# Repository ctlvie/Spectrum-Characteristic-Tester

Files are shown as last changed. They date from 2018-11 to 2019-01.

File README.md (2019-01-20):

# 基于MSP430的频率特性测试仪

## 摘要

频率特性测试仪用于测量并显示被测网络的频率特性，本设计由一个正交扫频DDS信号源产生两路正交的正弦信号，正弦信号的频率为1kHz～1MHz，且步进频率可调。其中一路正弦信号作为待测网络的激励，待测网络的输出分别与原先的两路正交信号相乘，经过低通滤波器后即可得到直流分量，再经过ADS1115采样并由MSP430F5529计算待测网络的幅值和相频特性曲线。待测网络为截止频率分别为10kHz和100kHz的二阶有源高通和低通滤波器串联而成。

The spectrum characteristic tester is used to measure and display the frequency characteristics of the network under test. This design generates two orthogonal sinusoidal signals from a quadrature swept DDS signal source. The frequency of the sinusoidal signal is 1 kHz to 1 MHz, and the step frequency can be Tune. One of the sinusoidal signals is used as the excitation of the network to be tested. The output of the network to be tested is respectively multiplied by the original two orthogonal signals. After passing through the low-pass filter, the DC component can be obtained, and then sampled by ADS1115 and calculated by MSP430F5529. The amplitude and phase-frequency characteristics of the network. The network to be tested is a series of second-order active high-pass and low-pass filters with cutoff frequencies of 10 kHz and 100 kHz, respectively.

## 作品报告

<https://github.com/ctlvie/Spectrum-Characteristic-Tester/wiki/%E5%9F%BA%E4%BA%8EMSP430%E7%9A%84%E9%A2%91%E7%8E%87%E7%89%B9%E6%80%A7%E6%B5%8B%E8%AF%95%E4%BB%AA>

## 程序清单

|文件名 | 功能描述 |
|---|---|
|main.c  | 主函数 |
| AD9854.c |DDS模块的驱动 |
|ADS1115.c|外接ADC模块的驱动|
|Board.c|MSP430F5529LP板上资源的配置|
|Button.c|四个按键的配置|
|FormatConvert.c|数据类型转换|
|GlobalTimer.c|定时器TimerB(记录测量用时)的配置|
|KeyBoard.c|外接4*4矩阵键盘的配置|
|LCD12864.c|液晶屏的驱动|
|ProcessModule.c|进行数据处理、计算、绘图|

## 系统结构

系统结构

## 实物图

实物图

曲线图

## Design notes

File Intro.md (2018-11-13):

## 试题要求
### 1. 任务
设计制作一台频率特性测试仪，用于测量并显示“被测网络”的频率特性。

### 2. 基本要求
1. 设计制作“被测网络”，其输入、输出阻抗均为 50Ω，该网络由截止频率10kHz的二阶有源高通滤波器与截止频率100kHz的二阶有源低通滤波器串联而成，两个有源滤波器通带电压增益均为1;
2. 频率特性测试仪中，“采样调理”电路的输入阻抗50Ω。“扫频信号发生器”输出振幅为1V的正弦电压，其扫频范围1kHz~1MHz，频率步进 10Hz或1kHz可选，输出阻抗50Ω，并可用键盘设定点频输出;
3. 用“扫频法”测量扫频范围内“被测网络”的幅频 特性，并在LCD上显示幅频特性曲线、截止频率值，测量时间≤10秒
### 3. 发挥部分
1. 采用“点频法”测量“被测网络”的电压增益，以数字方式显示被测网络增益与频率，并用示波器标定，测量相对误差≤5%;测量频率由键盘设定;
2. 用“扫频法”测量扫频范围内“被测网络”的相频特性，并在LCD上显示相频特性曲线，测量时间≤10秒;
3. 用“点频法”测量“被测网络”的相移，以数字方式显示被测网络的相移与频率，并用示波器标定，测量相对误差≤5%;测量频率由键盘设定;
### 4. 说明
* 扫频法是指扫频信号发生器输出等幅线性扫频信号作为被测网络输入，同时对被测网络输出响应信号采样和计算，测得被测网络的频率 特性(网络增益与频率的关系)的方法。点频法是指单频信号输入时逐个测得频率特性的方法；负载调整率SI1=|𝑈o2−𝑈o1|/ Uo1，其 中UO1 为Io=0A 时的输出电压， UO2为IO=2A 时的输出电压;
* 采用128×64点阵等规格LCD显示幅频特性或相频特性曲线时，应同时显示“增益_频率”或 “相移_频率”的线性刻度(刻度的单位自定)。
* 被测网络制作在单独供电的独立电路板上，其输入、输出信号分别焊接到BNC插座上;频率特性测试仪输入、输出信号分别焊接到BNC插座上。被测网络与频率特性测试仪之间用两根长度20~30cm、50Ω、BNC接头电缆连接。

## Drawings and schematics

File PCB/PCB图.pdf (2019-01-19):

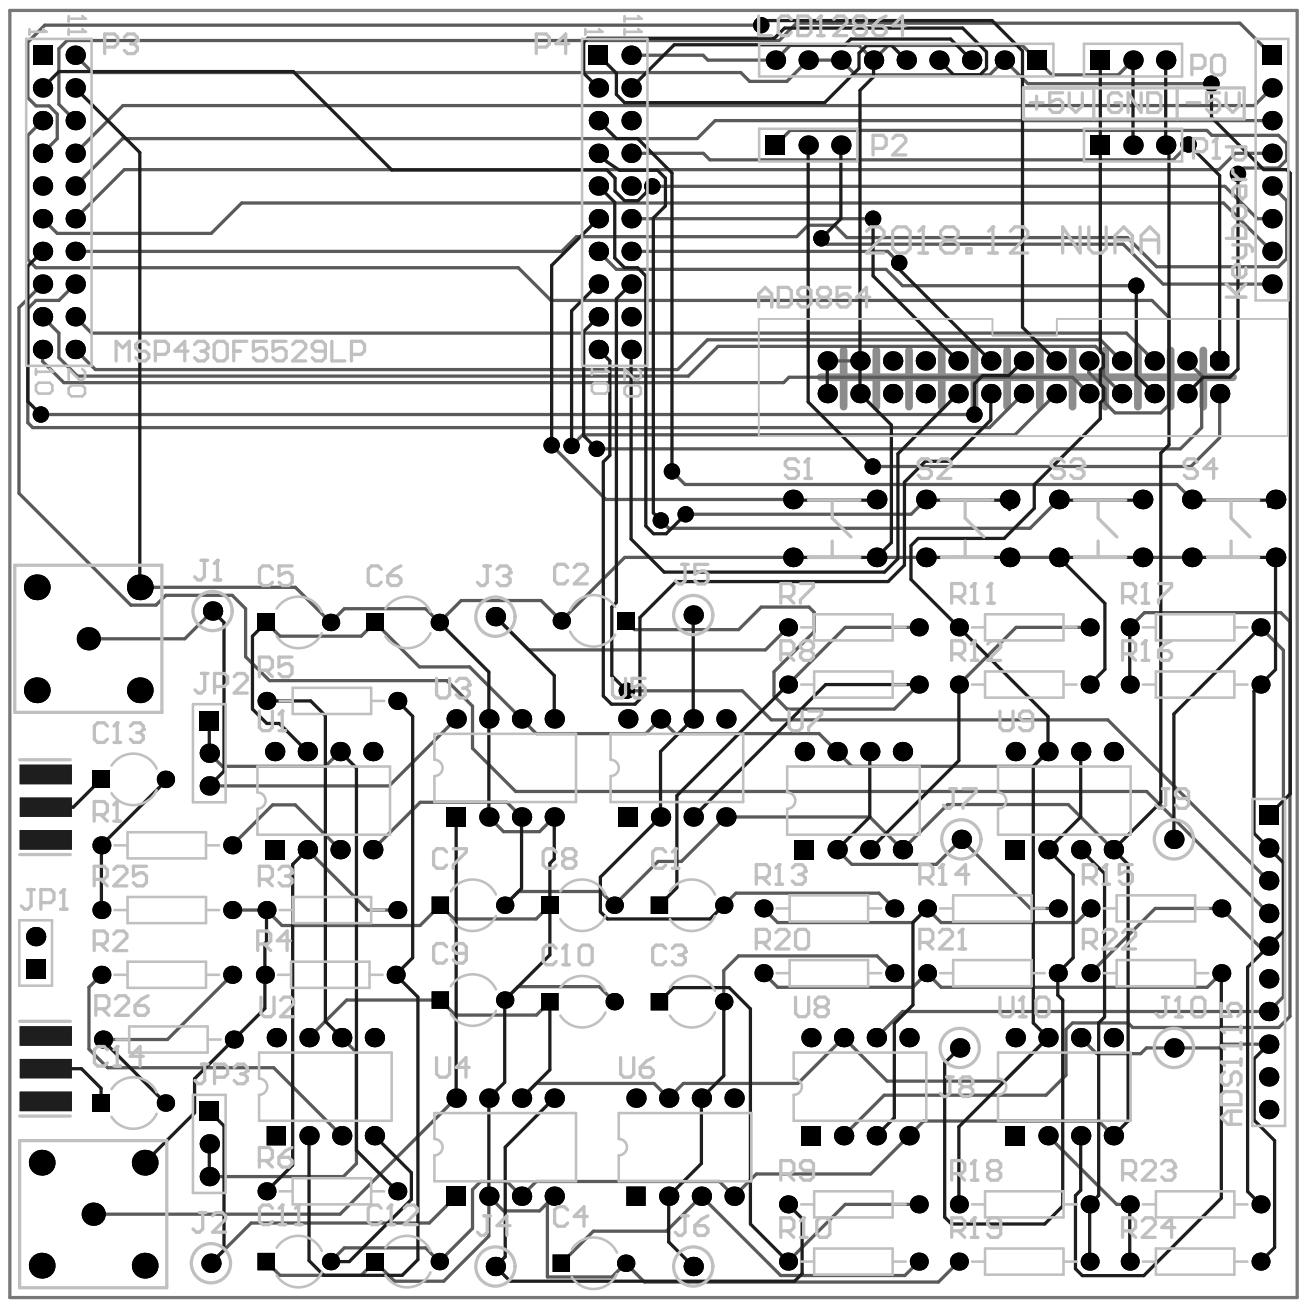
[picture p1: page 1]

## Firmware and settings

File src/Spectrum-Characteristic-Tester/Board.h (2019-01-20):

/*=======================================================
Author				  :				ctlvie
Email Address		  :				ctlvie@gmail.com
Filename			  :				Board.c
Date				  :			    2018-11-24
Description			  :				MSP430F5529LP ??????????

Modification History:
Date		By			Version		Description
----------------------------------------------------------
181124  	ctlvie		1.0			MSP430F5529LP ??????????
181216      ctlvie      2.0         Final Version
========================================================*/
#ifndef BOARD_H_
#define BOARD_H_

#define LED1_ON     P1OUT |= BIT0;
#define LED1_OFF    P1OUT |= BIT0;
#define LED2_ON     P4OUT |= BIT7;
#define LED2_OFF    P4OUT |= BIT7;

void initLED(void);
void initBoard(void);
#endif /* BOARD_H_ */

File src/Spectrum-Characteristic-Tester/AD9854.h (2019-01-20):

/*=======================================================
Author				  :				ctlvie
Email Address		  :				ctlvie@gmail.com
Filename			  :				AD9854.h
Date				  :			    2018-11-22
Description			  :				AD9854 DDS驱动程序

Modification History:
Date		By			Version		Description
----------------------------------------------------------
181122		ctlvie		1.0
181216      ctlvie      2.0         Final Version			
========================================================*/

#ifndef AD9854_H_
#define AD9854_H_
#ifndef uchar
#define uchar unsigned char
#endif
#ifndef ulong
#define ulong unsigned long
#endif
#ifndef uint
#define uint unsigned int
#endif

/*=======================================================
    接线方式:
    1. DataBus  ->  P3.0 ~ P3.7
    2. AddrBus  ->  P4.0 ~ P4.7
    3. RD       ->  P8.1
    4. WR       ->  P8.2
    5. UCLK     ->  P7.0
    6. RST      ->  P7.4
========================================================*/


#define IO_AD9854_DataBus_OUT       P3OUT
#define IO_AD9854_AddrBus_OUT       P4OUT
#define IO_AD9854_CtlBus1_OUT       P8OUT
#define IO_AD9854_CtlBus2_OUT       P7OUT
#define IO_AD9854_DataBus_DIR       P3DIR 
#define IO_AD9854_AddrBus_DIR       P4DIR
#define IO_AD9854_CtlBus1_DIR       P8DIR
#define IO_AD9854_CtlBus2_DIR       P7DIR

#define IO_AD9854_BIT_RD            BIT1
#define IO_AD9854_BIT_WR            BIT2
#define IO_AD9854_BIT_UCLK          BIT0
#define IO_AD9854_BIT_RST           BIT4



#define AD9854_DataBus              IO_AD9854_DataBus_OUT             //P3BIT0 ~ BIT7 为数据总线, 对应 D0 ~ D7
#define AD9854_AddrBus              IO_AD9854_AddrBus_OUT             //P4BIT0 ~ BIT5 为地址总线, 对应 A0 ~ A5
#define DIROUT_AD9854_DataBus       IO_AD9854_DataBus_DIR = BIT0 + BIT1 + BIT2 + BIT3 + BIT4 + BIT5 + BIT6 + BIT7 ;      //数据线IO口设为输出
#define DIROUT_AD9854_AddrBus       IO_AD9854_AddrBus_DIR = BIT0 + BIT1 + BIT2 + BIT3 + BIT4 + BIT5;     //地址线IO口设为输出
#define DIROUT_RD                   IO_AD9854_CtlBus1_DIR |= IO_AD9854_BIT_RD;    //P8.1 -> RD
#define DIROUT_WR                   IO_AD9854_CtlBus1_DIR |= IO_AD9854_BIT_WR;    //P8.2 -> WR
#define DIROUT_UDCLK                IO_AD9854_CtlBus2_DIR |= IO_AD9854_BIT_UCLK;    //P7.0 -> UCLK
#define DIROUT_RST                  IO_AD9854_CtlBus2_DIR |= IO_AD9854_BIT_RST;    //P7.4 -> RST
#define RD0_AD9854                  IO_AD9854_CtlBus1_OUT &= ~IO_AD9854_BIT_RD;   //RD使能(低有效)
#define RD1_AD9854                  IO_AD9854_CtlBus1_OUT |= IO_AD9854_BIT_RD;
#define WR0_AD9854                  IO_AD9854_CtlBus1_OUT &= ~IO_AD9854_BIT_WR;   //WR使能(低有效)
#define WR1_AD9854                  IO_AD9854_CtlBus1_OUT |= IO_AD9854_BIT_WR;
#define UCLK0_AD9854                IO_AD9854_CtlBus2_OUT &= ~IO_AD9854_BIT_UCLK;   //更新时钟
#define UCLK1_AD9854                IO_AD9854_CtlBus2_OUT |= IO_AD9854_BIT_UCLK;
#define RST0_AD9854                 IO_AD9854_CtlBus2_OUT &= ~IO_AD9854_BIT_RST;   //复位信号
#define RST1_AD9854                 IO_AD9854_CtlBus2_OUT |= IO_AD9854_BIT_RST;
//**************************以下部分为函数定义********************************

void WriteByte_AD9854(uchar addr,uchar dat);
void initAD9854(void);
void convertFreq(long Freq);
void setSinOutput(ulong Freq,uint Shape);
void convertFreq_double(double Freq);
void setSinOutput_double(double Freq,uint Shape);


//extern uchar FreqWord[6];              //6个字节频率控制字
//**********************以下为系统时钟以及其相关变量设置**************************

/*
      此处根据自己的需要设置系统时钟以及与其相关的因子，一次需且只需开启一个
      CLK_Set为时钟倍频设置，可设置4~20倍倍频，但最大不能超过300MHZ
      Freq_mult_ulong和Freq_mult_doulle均为2的48次方除以系统时钟，一个为长整形，一个为双精度型
*/

/*
#define      CLK_Set            4
const ulong  Freq_mult_ulong  = 3518437;
const double Freq_mult_doulle = 3518437.2088832;
*/

/*
#define      CLK_Set            5
const ulong  Freq_mult_ulong  = 2814750;
const double Freq_mult_doulle = 2814749.76710656;
*/

/*
#define      CLK_Set            6
const ulong  Freq_mult_ulong  = 2345625;
const double Freq_mult_doulle = 2345624.80592213;
*/

/*
#define      CLK_Set            7
const ulong  Freq_mult_ulong  = 2010536;
const double Freq_mult_doulle = 2010535.54793326;
*/

/*
#define      CLK_Set            8
const ulong  Freq_mult_ulong  = 1759219;
const double Freq_mult_doulle = 1759218.6044416;
*/

/*
#define      CLK_Set            9
const ulong  Freq_mult_ulong  = 1563750;
const double Freq_mult_doulle = 1563749.87061476;
*/

/*
#define      CLK_Set            10
const ulong  Freq_mult_ulong  = 1407375;
const double Freq_mult_doulle = 1407374.88355328;
*/

/*
#define      CLK_Set            11
const ulong  Freq_mult_ulong  = 1279432;
const double Freq_mult_doulle = 1279431.712321164;
*/

/*
#define      CLK_Set            12
const ulong  Freq_mult_ulong  = 1172812;
const double Freq_mult_doulle = 1172812.402961067;
*/

/*
#define      CLK_Set            13
const ulong  Freq_mult_ulong  = 1082596;
const double Freq_mult_doulle = 1082596.064271754;
*/


#define      CLK_Set            14
//extern ulong  Freq_mult_ulong  = 1005268;
//extern double Freq_mult_doulle = 1005267.773966629;


/*
#define      CLK_Set            15
const ulong  Freq_mult_ulong  = 938250;
const double Freq_mult_doulle = 938249.9223688533;
*/


#endif /* AD9854_H_ */

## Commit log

2018-11-13 完成被测网络的设计
2018-11-14 AD9854初始代码
2018-11-14 AD9854 编译通过
2018-11-16 键盘扫描
2018-11-16 键盘按键输入功能实现
2018-11-19 LCD12864 字符显示实现
2018-11-19 实现汉字显示和清屏
2018-11-19 实现任意点的绘制
2018-11-20 增加了画线函数，完善了注释部分
2018-11-20 ADS1115原始控制代码
2018-11-20 修正了延时函数名称
2018-11-20 ADS1115单通道转换功能实现
2018-11-20 增加ADC通道选择功能；修改ADS1115初始化函数
2018-11-20 实现float转换为字符串
2018-11-20 修复了初始化错误的bug
2018-11-20 增加LCD和ADS1115的测试函数
2018-11-21 电路设计
2018-11-21 PSpice 仿真
2018-11-21 乘法器与调理电路设计仿真
2018-11-21 AD9854 串行控制原始代码
2018-11-21 变量名称修改
2018-11-22 AD9854 串行模拟SPI编译通过
2018-11-22 更改命名方式
2018-11-22 回退至并行模式
2018-11-22 更新变量名称
2018-11-22 更改IO分配
2018-11-22 更新按键处理程序
2018-11-24 调整了AD9854接线方式, AD9854驱动实现
2018-11-24 按键处理 (未成功)
2018-11-24 修改按键扫描方式
2018-11-24 LaunchPad按键功能实现
2018-11-26 系统整体架构完成
2018-11-27 增加了Char到Int的转换
2018-11-27 修改新的引脚定义
2018-11-27 增加了数字输入功能
2018-11-27 扫频步进选择
2018-11-27 增加扫频测试函数
2018-11-27 ADC测试函数修改为双通道同时测试
2018-11-27 分10Hz和1kHz两档扫频测量(溢出错误,空间不足)
2018-11-27 增加了开平方和求解arctan的函数
2018-11-27 修正最后一行的bug
2018-11-27 扫频法幅度和相位的计算
2018-11-27 修复了x方向作图有断点的bug
2018-11-28 幅频线性,幅频对数,相频曲线绘制功能实现
2018-11-28 增加退出绘图模式的函数
2018-11-28 修复了清屏不完全的bug
2018-11-28 整合绘制曲线函数,增加显示坐标分度值的功能
2018-11-29 输入频率配置AD9854
2018-11-29 点频测量实现
2018-11-29 修复“0”无法识别的bug
2018-11-29 增加点频时的超范围提示
2018-11-29 扫频验证成功
2018-11-29 增加了清空缓冲区的函数，修复多次绘图重叠的bug
2018-11-29 程序主要框架与基本功能实现
2018-11-29 增加了dB图的绘制选择（坐标系存在问题）
2018-11-30 实现dB图绘制功能
2018-12-01 增加截止频率的计算
2018-12-10 修改键值配置
2018-12-10 增加扫频间隔等待时间
2018-12-10 基本功能完成
2018-12-11 增加了S4按键的定义
2018-12-11 增加三种曲线的放大模式
2018-12-12 增加了防止数组越界导致其他全局变量被异常修改的保护措施
2018-12-12 增加了三种曲线的放大查看模式
2018-12-12 增加了截止频率的计算函数
2018-12-13 修复了float转字符串时超出范围的bug
2018-12-13 修复了截止频率计算时int和float混合计算导致结果出错的bug
2018-12-13 计时器函数
2018-12-13 增加扫频用时的显示
2018-12-14 修改程序架构
2018-12-14 作品报告
2018-12-14 增加拟合函数
2018-12-14 优化键盘输入
2018-12-14 增加了游标显示
2018-12-14 优化点频输入时的游标显示
2018-12-14 增加自定义扫频
2018-12-14 修复自定义扫频时的图像显示bug
2018-12-15 修复了自定义扫频时刻度显示错误的bug
2018-12-15 增加使用S3键输入“0”的功能
2018-12-15 修改增益拟合函数
2018-12-15 修改英文表述
2018-12-16 修改扫频延时和时间显示参数
